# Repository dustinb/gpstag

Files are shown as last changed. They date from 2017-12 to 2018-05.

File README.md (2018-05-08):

Small device for logging GPS, speed, altitude, and gyro data.  Leaked photos

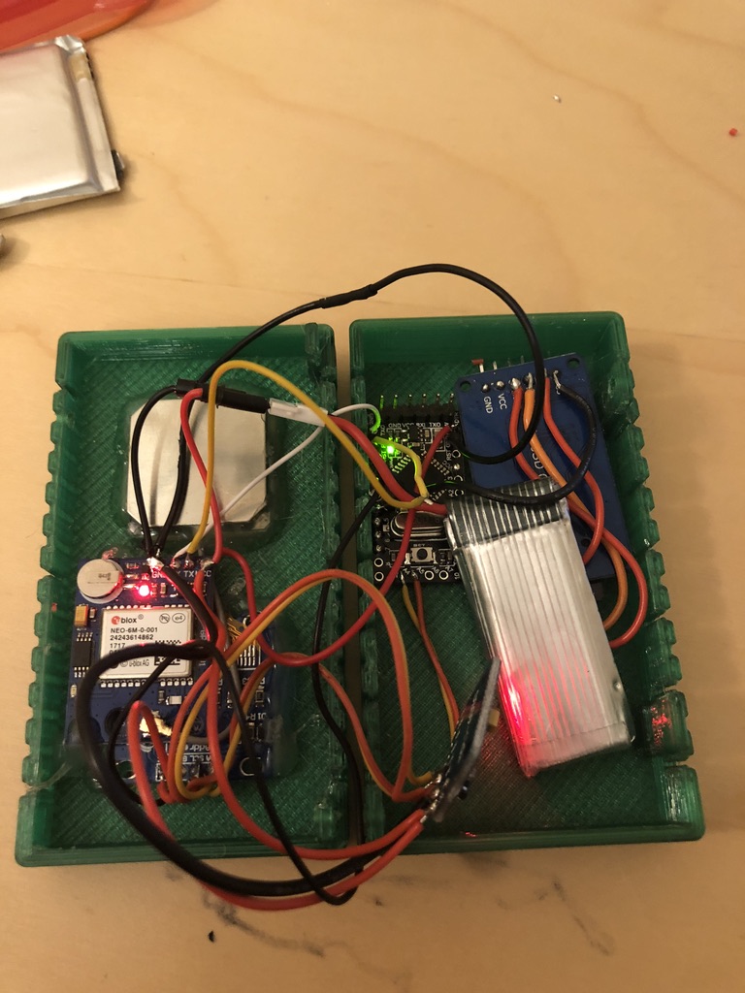
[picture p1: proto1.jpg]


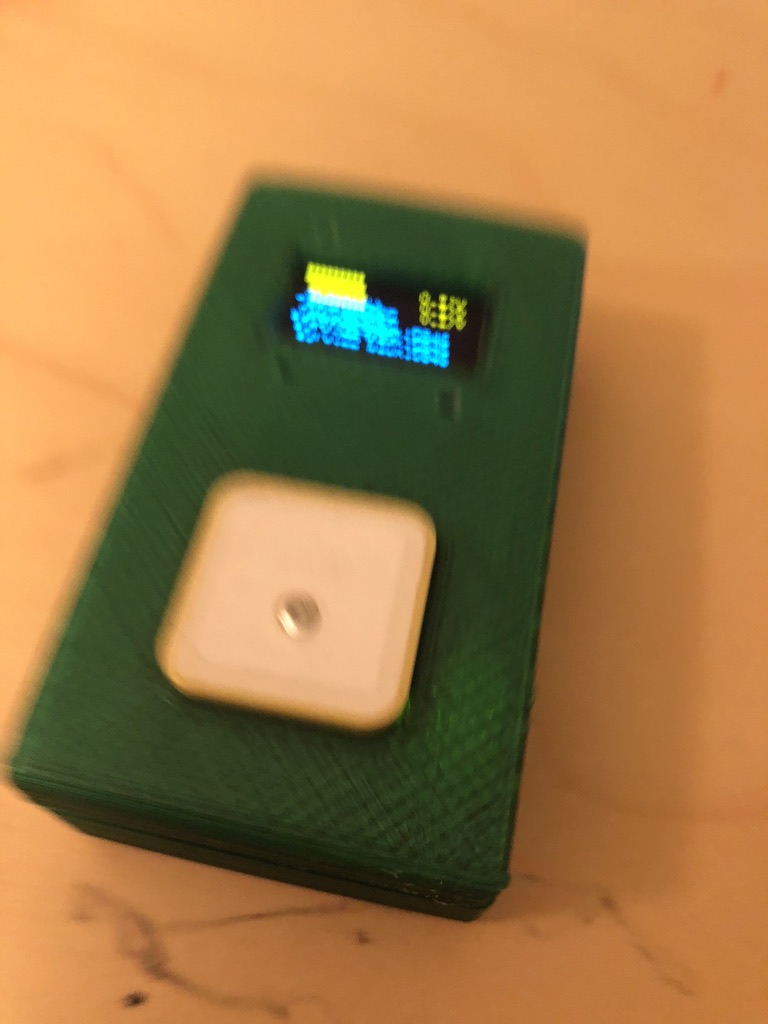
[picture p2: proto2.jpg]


# Dependencies

1. TinyGPS
2. Adafruit BMP085
3. U8glib

| Components | |
|---|---|
| 128x64 I2C OLED | http://amzn.to/2DCgqqy |
| 3.3 Volt Arduino Pro Mini | http://amzn.to/2Ekl7qn |
| BMP180 Barometer | http://amzn.to/2BZ5nHG |
| DIYMall U-blox Neo 6M GPS | http://amzn.to/2CuWlTX |
| U-blox Neo 6M GPS | http://amzn.to/2C2ikjG |
| SDCard SPI | http://amzn.to/2C6avK7 |
| Charge Module | http://amzn.to/2CpVUMZ |
| **Extras** ||
| LED, Resistors, Buttons | http://amzn.to/2Cgyuu4 |
| USB 3.3/5v FTDI | http://amzn.to/2CkjBpZ |

# Power

All components will be direct to battery using built in regulators. Bat+ -> RAW to power the Pro Mini.  Waypoint button
and LED powered from VCC.

## Arudino

From what I've read the Pro Mini RAW input regulator will work down to 3.5V.  Seems all the components have 
their own 3.3V regulator or can handle voltage ranges from the 1s lipo (@3.3V - 4.2V).

Reading voltage with divider described here [here](https://forum.arduino.cc/index.php?topic=420527.0)

    // Added the 1.008 as adjustment from measured voltage
    (analogRead(pin)*ARef/1024.0) * (R1+R2)/R2 * 1.008

## DIYmall GPS

This module seems very sensitive to voltages close to or under 3.3v.  When running all the components via Arduino VCC 
was hit or miss to get any satellites.

The Neo 6M module [specs](https://www.u-blox.com/sites/default/files/products/documents/NEO-6_DataSheet_%28GPS.G6-HW-09005%29.pdf)
The DIYmall version listed has input of 3V to 5V volts.

## DIYmall OLED

3.3V to 5V volts so running direct from 1s lipo which will be **3.3** to **4.2**

## BMP180

One listed has 3.3v regulator

# Prototyping

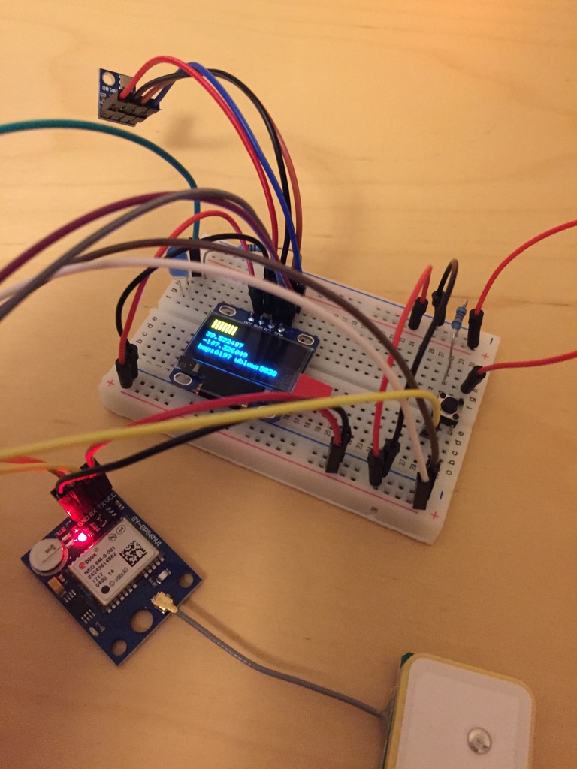
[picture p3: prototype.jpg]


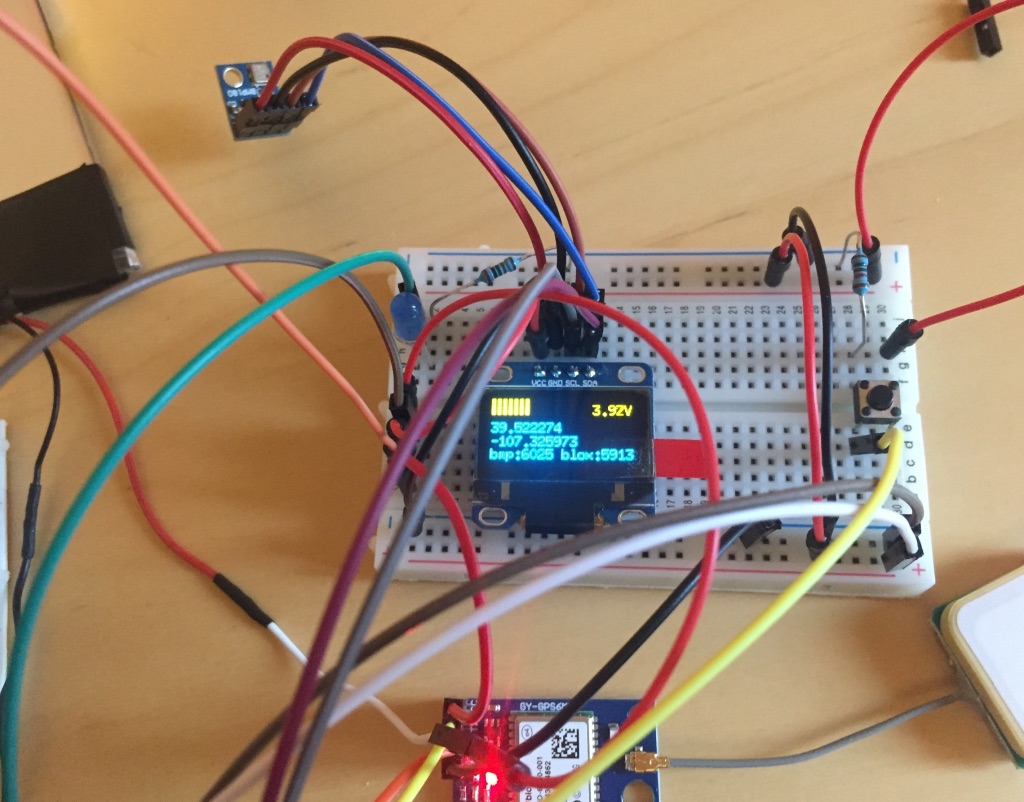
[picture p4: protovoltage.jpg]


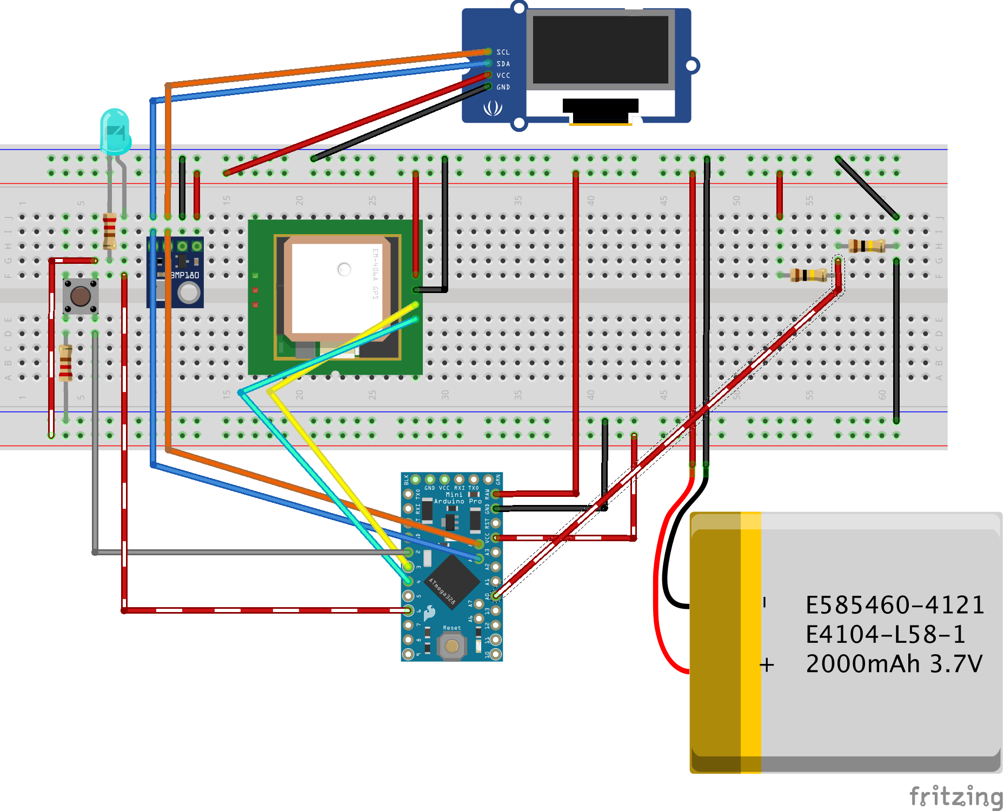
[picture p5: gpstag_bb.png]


# Enclosure Notes

Ublox Antenna 25 x 25mm with 3mm fillet

Screen 27 x 15mm

Screen Mounting Holes are about 20mm x 22mm center

      O------- 20mm -------O
      |  2mm               |
      |---- Screen Top ----|
      |                    |
    22mm                   |
      |                    |
      |---- Screen Bot ----|
      |  6mm               |
      |                    |
      O ------- 20mm ------O

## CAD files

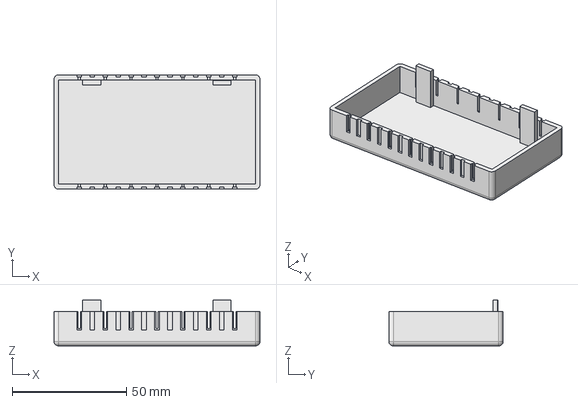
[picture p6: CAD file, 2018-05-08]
enclosure/Case Half V2.FCStd
90.0 x 50.0 x 20.0 mm

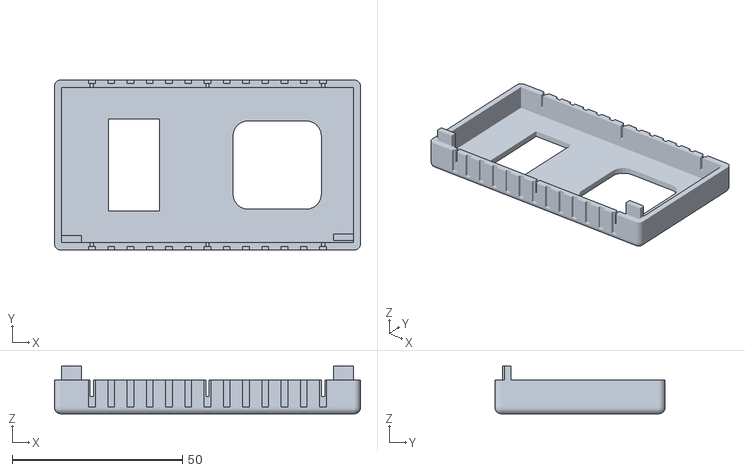
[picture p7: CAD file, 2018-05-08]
enclosure/Case Half.stl
90.0 x 50.0 x 14.0

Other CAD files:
enclosure/Case Half Mounts.FCStd
enclosure/Blank Half.stl

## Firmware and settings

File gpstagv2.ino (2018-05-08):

// Using SPI bus for multiple devices
// https://learn.sparkfun.com/tutorials/serial-peripheral-interface-spi

/*
 * UBLOX Neo 6m 9600 Baud
 * VCC - BAT
 * TX  - RxPin or RX1 
 * RX  - TxPin or TX0
 * GND
 */
#include <TinyGPS++.h>
TinyGPSPlus gps;

#define SDCARD
#ifdef SDCARD
  #include <SPI.h>
  #include <SD.h>
#endif

/*
 * SDA - A4
 * SCL - A5
 * GND
 * VCC - BAT
 */
#define OLED
#ifdef OLED
  #include "U8glib.h"
  U8GLIB_SSD1306_128X64 u8g(U8G_I2C_OPT_DEV_0|U8G_I2C_OPT_NO_ACK|U8G_I2C_OPT_FAST);  // Fast I2C / TWI
#endif

/*
 * BMP180
 * SDA - A4
 * SLC - A5
 * GND
 * VCC - BAT
 */
//#define BMP180
#ifdef BMP180
  #include <Adafruit_BMP085.h>
  Adafruit_BMP085 bmp;
#endif

const int RXPin = 3, TXPin = 4;
const uint32_t GPSBaud = 9600;
const int wayPointButton = 2;
const int ledPin = 6;
float batteryVoltage = 0;
String dataString = "";
int doLog = 0;

// The serial connection to the GPS device
#define HWSERIAL
#ifndef HWSERIAL
  #include <SoftwareSerial.h>
  SoftwareSerial ss(RXPin, TXPin);
#endif

void setup() {

  pinMode(wayPointButton, INPUT);
  pinMode(ledPin, OUTPUT);
  pinMode(A0, INPUT);

  #ifdef SDCARD
    SD.begin(10);
  #endif
    
  #ifdef BMP180
    if (! bmp.begin()) {
      while (1) {}
    }
  #endif
   
  // Either GPS or for debugging
  Serial.begin(GPSBaud);

  // If using Software Serial (RXPin/TXPin) we can output debugging information on hardware serial via FTDI
  #ifndef HWSERIAL
    ss.begin(GPSBaud);
    Serial.print("Setup");
  #endif

  return;
  // Wait for GPS lock
  int page = 0;
  while(! gps.location.isValid()) {
    // Print page++ up to 3-4 pages and repeat
    if (page > 2) page = 0;
    draw(page++);
    smartDelay(3000);
  }
}

void draw(int page) {
  #ifndef OLED
    return;
  #endif

  u8g.firstPage();
  do {
    switch (page) {
      case 0:
        u8g.setColorIndex(1);
        u8g.setFont(u8g_font_7x13);
        u8g.setPrintPos(0, 13);
        u8g.print("gpstag v0.8.1");
        u8g.setPrintPos(0, 35);
        u8g.print("got satellites? ...");
        break;
      case 1:
        u8g.setPrintPos(0, 50);
        u8g.print("Bueller? ...");
        break;
      case 2:  
        u8g.setPrintPos(0, 50);
        u8g.print("Fry? ..."); 
        break;
      case 9:   
        for (int i=1; i<=gps.satellites.value(); i++) {
          if (i % 2 == 0) {
           u8g.drawBox(i*5, 0, 3, 15);  
          } else {
           u8g.drawBox(i*5, 4, 3, 11); 
          }
        }

        // Last battery voltage reading
        u8g.setPrintPos(90, 15);
        u8g.print(batteryVoltage);
        u8g.print("V");
        u8g.setPrintPos(0, 30);
        u8g.print(gps.location.lat(), 6);
        u8g.setPrintPos(0, 43);
        u8g.print(gps.location.lng(), 6);
        u8g.setPrintPos(0, 55);
        #ifdef BMP180
          u8g.print("bmp:");
          u8g.print((int) (bmp.readAltitude(103200) * 3.28084));
        #endif
      
        u8g.print(" blox:");
        u8g.print((int) gps.altitude.feet());
        break;
    }
  } while( u8g.nextPage() );
}

void loop() {

  // TODO: Log GPS lat/long elevation timestamp to sdcard
  // Review GPS standards for logging https://en.wikipedia.org/wiki/GPS_Exchange_Format
  
  dataString = String(gps.location.lat(), 6);
  dataString += ',';
  dataString += String(gps.location.lng(), 6);
  dataString += ',';
  dataString += String(gps.altitude.feet());
  dataString += ',';
  char GPSDate[10];
  TinyGPSDate d = gps.date;
  sprintf(GPSDate, "%02d-%02d-%02d", d.year(), d.month(), d.day());
  dataString += String(GPSDate);
  TinyGPSTime t = gps.time;
  char GPSTime[8];
  sprintf(GPSTime, " %02d:%02d:%02d ", t.hour(), t.minute(), t.second());
  dataString += String(GPSTime)  ;
      
  if (digitalRead(wayPointButton) == HIGH) {
    // turn LED on so we know the waypoint is getting logged
    digitalWrite(ledPin, HIGH);
    doLog++;
    dataString += ",1";
    
    // TODO: Log waypoint to sdcard
    #ifndef HWSERIAL
      Serial.println(gps.location.lat());
      Serial.println(gps.location.lng());
    #endif  
  }

  #ifdef SDCARD
    if (doLog) {
      File dataFile = SD.open("tracking.txt", FILE_WRITE);
      dataFile.println(dataString);
      dataFile.close();
    }
  #endif

  // Voltage divider circuit R1 = 2K R2 = 5.1K 3.02V at 4.2 volts
  // http://tinyurl.com/y82a9s59
  // Try to smooth out the reading using our loop delay here
  batteryVoltage = 0;
  for(int i=0; i<10; i++) {
    batteryVoltage += (analogRead(A0) * 3.3 /1024.0) * (2000 + 5100) / 5100;
    smartDelay(200);
  }
  batteryVoltage = batteryVoltage / 10;

  // Draw main screen
  draw(9);
  
  // LED Off
  digitalWrite(ledPin, LOW); 
}

// This custom version of delay() ensures that the gps object is being "fed" data while we wait.
static void smartDelay(unsigned long ms) {
  unsigned long start = millis();
  while (millis() - start < ms) {
    #ifndef HWSERIAL
      while(ss.available()) {
        gps.encode(ss.read());
      }
    #else
      while(Serial.available()) {
        gps.encode(Serial.read());
      }
    #endif
  }
}

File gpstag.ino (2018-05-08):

#include <MPU6050_tockn.h>
#include <Wire.h>

MPU6050 mpu6050(Wire);

#define OLED
//#define BMP180
#define HWSERIAL

// Using SPI bus for multiple devices
// https://learn.sparkfun.com/tutorials/serial-peripheral-interface-spi

#include <TinyGPS++.h>

/*
 * SDA - A4
 * SCL - A5
 * GND
 * VCC - RAW
 */
#ifdef OLED
  #include "U8glib.h"
  float volts = 0;         // Voltage reading
  const float ARef = 3.3;  // 3.3v reference default for 3.3v mini
  const int R1 = 100;      // 100K
  const int R2 = 100;      // 100K
#endif

/*
 * BMP180
 * SDA - A4
 * SLC - A5
 * GND
 * VCC - RAW
 */
#ifdef BMP180
  #include <Adafruit_BMP085.h>
#endif

/*
 * UBLOX Neo 6m 9600 Baud
 * VCC - 3.3v
 * TX  - RxPin or RX1 
 * RX  - TxPin or TX0
 */

static const int RXPin = 3, TXPin = 4;
static const uint32_t GPSBaud = 9600;
static const int wayPointButton = 2;
static const int ledPin = 6;

// The TinyGPS++ object
TinyGPSPlus gps;

// The serial connection to the GPS device
// TODO: Change to hardware serial
#ifndef HWSERIAL
  #include <SoftwareSerial.h>
  SoftwareSerial ss(RXPin, TXPin);
#endif

// Our oled display
#ifdef OLED
  // U8G_I2C_OPT_DEV_0|U8G_I2C_OPT_NO_ACK|U8G_I2C_OPT_FAST
  U8GLIB_SSD1306_128X64 u8g(U8G_I2C_OPT_DEV_0|U8G_I2C_OPT_NO_ACK|U8G_I2C_OPT_FAST);  // Fast I2C / TWI
  //U8G2_SSD1306_128X64_NONAME_1_HW_I2C u8g(U8G2_R0);
#endif

#ifdef BMP180
  // Barameter for temp, pressure, altitude
  Adafruit_BMP085 bmp;
#endif

void setup() {

  pinMode(wayPointButton, INPUT);
  pinMode(ledPin, OUTPUT);
  pinMode(A0, INPUT);
  
  #ifdef BMP180
    if (! bmp.begin()) {
      while (1) {}
    }
  #endif
   
  #ifdef OLED
    u8g.setColorIndex(1);
    u8g.setFont(u8g_font_7x13);
  #endif

  // Either GPS or for debugging
  Serial.begin(GPSBaud);

  // If using Software Serial (RXPin/TXPin) we can output debugging information
  #ifndef HWSERIAL
    ss.begin(GPSBaud);
    Serial.print("Setup");
  #endif  

  Wire.begin();
  mpu6050.begin();
  mpu6050.calcGyroOffsets(false);
}

void loop() {

  if (digitalRead(wayPointButton) == HIGH) {
    // turn LED on so we know the waypoint is getting logged
    digitalWrite(ledPin, HIGH);
    
    // TODO: Log waypoint to sdcard
    #ifndef HWSERIAL
      Serial.println(gps.location.lat());
      Serial.println(gps.location.lng());
    #endif 
    delay(1000); // Delay to indicate we logged waypoint 
  }
  
  // TODO: Log GPS lat/long elevation timestamp to sdcard
  // Review GPS standards for logging https://en.wikipedia.org/wiki/GPS_Exchange_Format

   mpu6050.update();
   
  #ifdef OLED
    u8g.firstPage();
    do {
      // Box for each satellite
      for (int i=0; i<gps.satellites.value(); i++) {
        u8g.drawBox(i*5, 0, 3, 15);
      }

      volts = (analogRead(A0)*ARef/1024.0) * (R1+R2)/R2 * 1.008;
     
      u8g.setPrintPos(90, 15);
      u8g.print(volts);
      u8g.print("V");
      
      u8g.setPrintPos(0, 30);
      u8g.print(gps.location.lat(), 6);
    
      u8g.setPrintPos(0, 43);
      u8g.print(gps.location.lng(), 6);
      
      u8g.setPrintPos(0, 55);

      u8g.print("gyro:");
      u8g.print((int) mpu6050.getGyroX());
      
      
      #ifdef BMP180
        u8g.print("bmp:");
        u8g.print((int) (bmp.readAltitude(103200) * 3.28084));
      #endif
      
      u8g.print(" blox:");
      u8g.print((int) gps.altitude.feet());
    } while( u8g.nextPage() );
  #endif

  digitalWrite(ledPin, LOW); 
  smartDelay(1800);
}

// This custom version of delay() ensures that the gps object is being "fed" data while we wait.
static void smartDelay(unsigned long ms) {
  unsigned long start = millis();
  while (millis() - start < ms) {
    #ifndef HWSERIAL
      while(ss.available()) {
        gps.encode(ss.read());
      }
    #else
      while(Serial.available()) {
        gps.encode(Serial.read());
      }
    #endif
  }
}

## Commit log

2017-12-31 Initial prototyping
    [Case Half.stl]
2017-12-31 Update enclosure with mounting holes
    [Case Half.stl]
2018-01-02 Adding voltage read to display. Add fritzing prototype layout. Add FreeCAD files for enclosure.
    [Case Half Mounts.FCStd, Case Half V2.FCStd, gpstag.fzz]
2018-05-08 Added mpu 6050 gyro, testing read
    [Blank Half.stl, Case Half Mounts.FCStd, Case Half V2.FCStd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]
